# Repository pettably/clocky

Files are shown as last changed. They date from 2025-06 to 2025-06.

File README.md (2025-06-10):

# clocky

Simple desk and gym timer made with a LilyGO T-Display-S3-Long on Esphome.

I'm using an 18650 battery to power the display and I 3D printed a small enclosure for it all (STL File included) plus added a small USB C socket on the back which i soldered onto the VCC and GND terminals next to the USB C socket on the rear of the display. 
Just a note that the USB C socket will only work on chargers that aren't "smart" like power delivery. I use an old iPhone charging brick.

# Functions

Stopwatch 

Timer - Presets at the bottom of the display for 1, 2, 3 and 5 minutes

Interval - Select workout time of 1, 2, 3 minutes, cycles of 1, 2 or 3, and rest times of 30 seconds, 1 and 2 minutes.

Pomodoro - Basic Pomodoro timer. 25 minutes "BUSY", 5 minutes "REST"

Notifications - Notifications from Home Assistant are availible. I have phone calls make the screen red and say "ON A CALL"

# Issues that were resolved

Esphome removed external componants, but luckily there is now a native componant for the display.

Display must be set as 20Mhz. Any higher wont show correctly

Timers resetting themselves - I noticed that the screen is pushing against the enclosure which was causing ghost touches. Just had to pull the screen forward a bit.

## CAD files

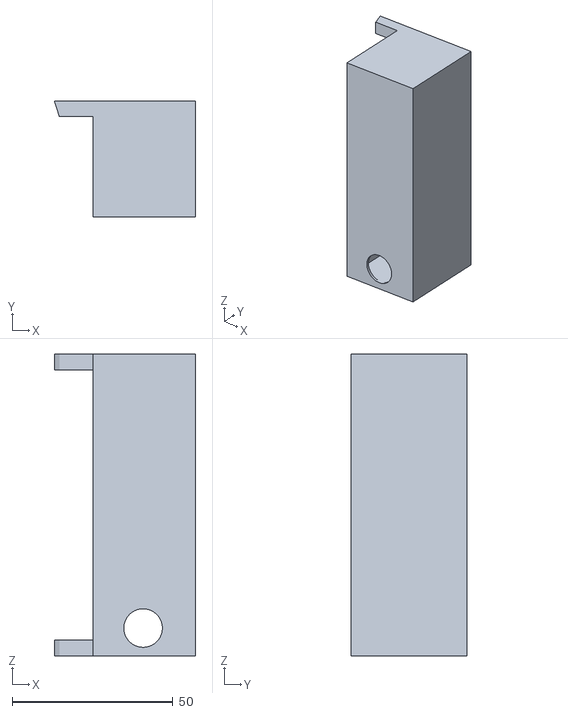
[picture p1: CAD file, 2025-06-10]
Clocky.stl
44.0 x 36.0 x 94.0

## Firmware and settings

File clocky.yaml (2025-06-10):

api:
  encryption:
    key: !secret clocky_api

ota:
  - platform: esphome
    password: !secret clocky_ota

substitutions:

# Device customization

  background_color: '000000'


esphome:
  name: clocky
  friendly_name: Clocky
  platformio_options:
    upload_speed: 921600
    build_unflags: -Werror=all
    board_build.flash_mode: qio
    board_build.prsam_type: opi
    board_build.f_flash: 80000000L
    board_build.f_cpu: 240000000L

# Board must be set as devkit

esp32:
  board: esp32-s3-devkitc-1
  flash_size: 16MB
  cpu_frequency: 240MHZ
  framework:
    type: esp-idf
    advanced:
      enable_idf_experimental_features: true

# Enable logging

logger:
  level: DEBUG
  logs:
    esphome: INFO
    "esphome.timer": DEBUG
    "esphome.text_sensor": DEBUG

# WiFi configuration

wifi:
  networks:
    - ssid: !secret wifi_ssid
      password: !secret wifi_password
      priority: 1
    - ssid: !secret wifi_ssid_2
      password: !secret wifi_password_2
      priority: 0

# Enable fallback hotspot (captive portal) in case wifi connection fails
  ap:
    ssid: "Clocky Fallback Hotspot"
    password: "fallback"

captive_portal:

# Wireguard configuration. This is used to encrypt the connection between the ESP32 and the Home Assistant server.
# Currently cant get this working. Must set reboot timeout as 0s or the device reboots itself 

#wireguard:
#  address: 10.0.0.4
#  private_key: !secret wg_private_key
#  peer_endpoint: !secret wg_endpoint
#  peer_public_key: !secret wg_public_key
#  peer_port: 33353  # Add explicit port number
#  netmask: 0.0.0.0
#  reboot_timeout: 0s


# Display set-up. Display is Quad_SPI with 4 data pins. The display is a AXS15231. This is now supported in ESPHome.
# The display is connected to the ESP32-S3 via the QSPI interface. The display is 640x180 pixels.

spi:
  id: quad_spi
  clk_pin: 17
  type: quad
  data_pins: [13, 18, 21, 14]

i2c:
  - sda: 9
    scl: 48
    id: lily_i2c
  - sda: 15
    scl: 10
    id: touch_i2c

touchscreen:
  - platform: axs15231
    id: lily_touch
    display: lily_display
    i2c_id: touch_i2c
    interrupt_pin: GPIO11
    transform:
      mirror_x: false
      mirror_y: false
      swap_xy: false
    on_touch:
      - lambda: |-
            ESP_LOGI("cal", "x=%d, y=%d, x_raw=%d, y_raw=%0d",
            touch.x,
            touch.y,
            touch.x_raw,
            touch.y_raw
            );

# Speed to be set to 80MHz. 120MHz is not supported and usually results in falling back to 40MHz.

psram:
  mode: octal
  speed: 80MHz
  enable_ecc: True

output:
  - platform: ledc
    pin: GPIO1
    id: backlight_pwm
    frequency: 100Hz  #Datasheet suggests low-frequency PWM. Should prevent stability issues.

light:
  - platform: monochromatic
    output: backlight_pwm
    name: Display
    id: backlight
    restore_mode: ALWAYS_ON
    internal: True

# NTP Time server

time:
  - platform: sntp
    id: sntp_time
    timezone: "Australia/Sydney"
    servers:
      - pool.ntp.org
      - au.pool.ntp.org
    on_time:
      - seconds: 0
        minutes: /1
        then:
          - lambda: |-
              id(lily_display).update();  // Force update every minute

globals:
  - id: show_notification
    type: bool
    restore_value: no
    initial_value: 'false'
  - id: notification_timeout
    type: int
    restore_value: no
    initial_value: '0'
  - id: is_persistent_notification
    type: bool
    restore_value: no
    initial_value: 'false'
  - id: current_page
    type: std::string
    restore_value: no
    initial_value: '"home"'

# STOPWATCH

  - id: stopwatch_time
    type: int
    restore_value: no
    initial_value: '0'
  - id: stopwatch_running
    type: bool
    restore_value: no
    initial_value: 'false'

# TIMER
  - id: timer_time
    type: int
    restore_value: no
    initial_value: '60'
  - id: timer_running
    type: bool
    restore_value: yes
    initial_value: 'false'
  - id: timer_flash_count
    type: int
    restore_value: yes
    initial_value: '0'
  - id: timer_flash_state
    type: bool
    restore_value: yes
    initial_value: 'false'
  - id: selected_timer_time
    type: int
    restore_value: yes
    initial_value: '60'  # Default to 1 minute
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
